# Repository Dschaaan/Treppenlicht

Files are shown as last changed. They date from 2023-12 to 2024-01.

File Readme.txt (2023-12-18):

Treppenlicht

An automatic staircase illumination system using an arduino and LED strips coupled with motion sensors

Content: 
Fritzing File: 	Here the schematic setup of the wiring and the components is shown 
Main Code: 	The code uploaded to the arduino Test Code: For all important components, 
		a testing file will be included Component list: All used components with important explanations

Generall Stuff: 
The idea is to have a motion triggered LED illumination of all steps in the staircase, which only can only be 
activated after a defined time of day. When the bottom motion sensor is activated, the stairs shall be illuminated 
from the bottom to the top and stay on for a defined duration. Afterwards the step lights are turned off in the 
same order as they turned on. Vice verca if the top sensor is activated first.

The working principle is based on the the HC-SR501 PIR Module as a motion sensor, which gives a signal to the 
arduino when activated. The arduino is connected to a PCA9685 16 Channel PWM Driver, which outputs the PMW signal 
for up to 16 steps. To activate the LEDs, they are connected to a logic level MOSFET (IRLZ44N) and respective 
pull-down resistor.

Notes:
- The 12V LEDs are quite bright, but with an additional resistor, the brightness is better suited. 
- Still need a 5V conversion - test the 7508 converter
-

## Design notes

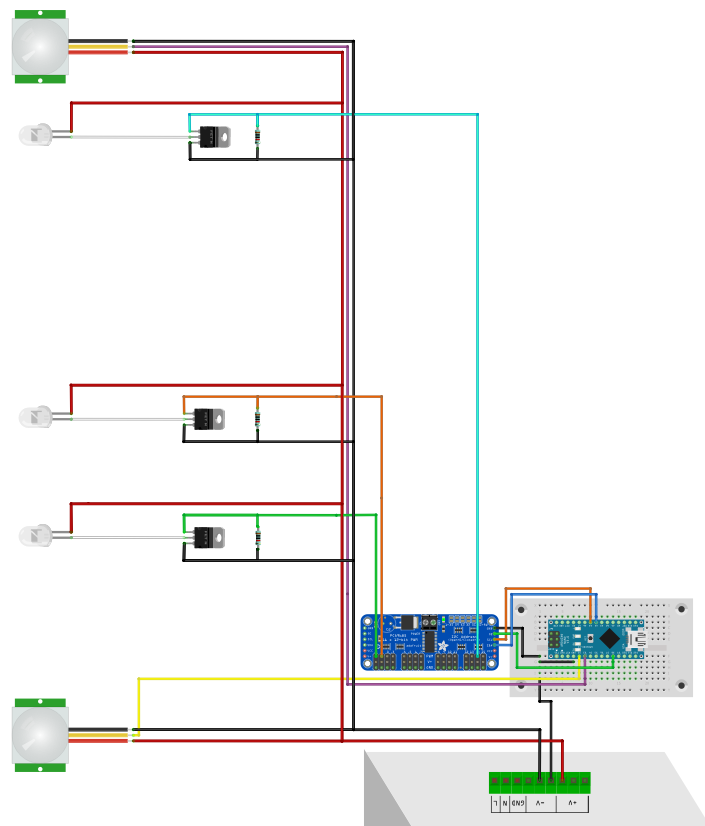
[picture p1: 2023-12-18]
Schaltplan.png

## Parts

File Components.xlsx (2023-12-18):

Treppenlicht Components
Component | # | Price p.p | total | Link | Datasheet
Arduino Nano V3 | 1 | 2.51 € | 2.51 € | https://de.aliexpress.com/item/1005006053215107.html
PIR HC-SR501 | 1 | 2.66 € | 2.66 € | https://de.aliexpress.com/item/1005005970452298.html
PMW PCA9685 16 Kanal | 2 | 2.60 € | 5.20 € | https://www.aliexpress.com/item/1005005973866782.html
Netzteil 200W | 1 | 24.99 € | 24.99 € | https://www.amazon.de/dp/B09Q92KW1H?psc=1&ref=ppx_yo2ov_dt_b_product_details
COB LED 12V 15m | 1 | 25.00 € | 25.00 € | https://www.aliexpress.com/item/1005004635579613.html
MOSFET ILRZ44N | 15 | 1.10 € | 16.50 € | https://www.amazon.de/dp/B0CBKH4XGL?psc=1&ref=ppx_yo2ov_dt_b_product_details
10kO Resistor | 15 |  | 25.00 € | https://www.amazon.de/dp/B08FD4KHP2?psc=1&ref=ppx_yo2ov_dt_b_product_details
Wires & Connectors |  |  |  | https://www.amazon.de/dp/B0B4DFTTDR?psc=1&ref=ppx_yo2ov_dt_b_product_details
 |  |  |  | https://www.amazon.de/dp/B00C7NVYV2?psc=1&ref=ppx_yo2ov_dt_b_product_details
 |  |  |  | https://www.amazon.de/dp/B07D7G8ZJ7?psc=1&ref=ppx_yo2ov_dt_b_product_details
LED Profiles (optional) | 15 | 3.00 € | 44.98 €
 |  |  | 146.84 € | SUMME

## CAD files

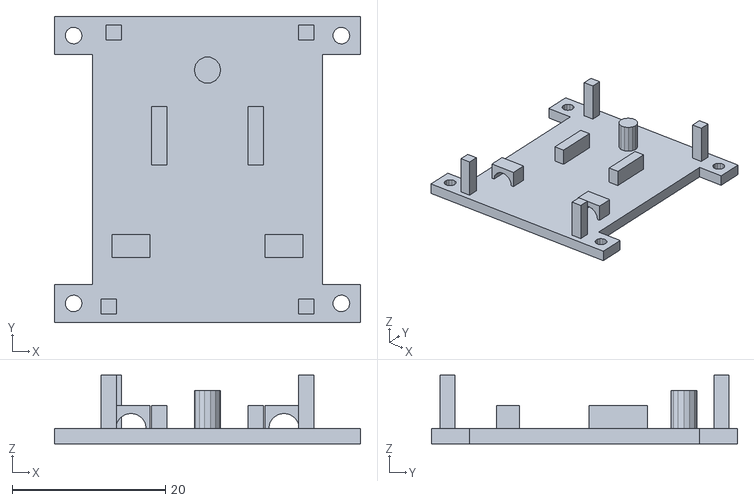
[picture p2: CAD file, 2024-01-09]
STL FIles/Boden Mosfet.stl
40.0 x 40.0 x 9.00

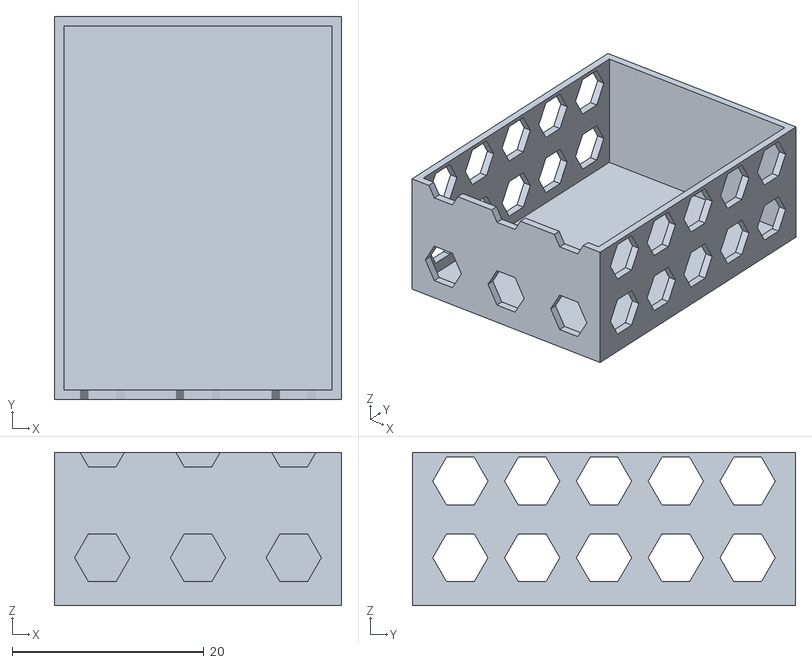
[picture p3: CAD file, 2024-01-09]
STL FIles/Deckel Mosfet.stl
30.0 x 40.0 x 16.0

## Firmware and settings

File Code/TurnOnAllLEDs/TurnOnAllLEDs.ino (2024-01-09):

// 2019 Tobias Kuch GPL 3.0
#include <Wire.h>

#define PWM_Module_Base_Addr 0x40 //10000000b  Das letzte Bit des Adressbytes definiert die auszuführende Operation. Bei Einstellung auf logisch 1  0x41 Modul 2
//wird ein Lesevorgang auswählt, während eine logische 0 eine Schreiboperation auswählt.
#define OE_Pin  8           // Pin für Output Enable
#define PIRA_Pin 2
#define PIRB_Pin 3

#define Num_Stages  15
#define Ontime 3000
#define Delay_Stages  10
#define Delay_ON_to_OFF  30  // Minimum Delay_ON_to_OFF in Seconds

byte Pwm_Channel = 0;
int Pwm_Channel_Brightness = 0;

bool Motion_Trigger_Down_to_Up = false;
bool On_Delay = false;

// interrupt Control
byte A60telSeconds24 = 0;
byte Seconds24;

ISR(TIMER1_COMPA_vect)
{
  A60telSeconds24++;
  if (A60telSeconds24 > 59)
  {
    A60telSeconds24 = 0;
    Seconds24++;
    if (Seconds24 > 150)
    {
      Seconds24 = 0;
    }
  }
}

void ISR_PIR_A()
{
  bool PinState = digitalRead(PIRA_Pin);
  if (PinState)
  {
    Motion_Trigger_Down_to_Up = true; // PIR A ausgelöst
  }
}

void ISR_PIR_B()
{
  bool PinState = digitalRead(PIRB_Pin);
  if (PinState)
  {
    Motion_Trigger_Down_to_Up = true; // PIR B ausgelöst
  }
}

void Init_PWM_Module(byte PWM_ModuleAddr)
{
  pinMode(OE_Pin, OUTPUT);
  digitalWrite(OE_Pin, HIGH); // Active LOW-Ausgangsaktivierungs-Pin (OE).
  Wire.beginTransmission(PWM_ModuleAddr); // Datentransfer initiieren
  Wire.write(0x01);                       // Wähle  Mode 2 Register (Command Register)
  Wire.write(0x04);                       // Konfiguriere Chip: 0x04:  totem pole Ausgang 0x00: Open drain Ausgang.
  Wire.endTransmission();                 // Stoppe Kommunikation - Sende Stop Bit
  Wire.beginTransmission(PWM_ModuleAddr); // Datentransfer initiieren
  Wire.write(0x00);                      // Wähle Mode 1 Register (Command Register)
  Wire.write(0x10);                      // Konfiguriere SleepMode
  Wire.endTransmission();                // Stoppe Kommunikation - Sende Stop Bit
  Wire.beginTransmission(PWM_ModuleAddr); // Datentransfer initiieren
  Wire.write(0xFE);                       // Wähle PRE_SCALE register (Command Register)
  Wire.write(0x03);                       // Set Prescaler. Die maximale PWM Frequent ist 1526 Hz wenn das PRE_SCALEer Regsiter auf "0x03h" gesetzt wird. Standard : 200 Hz
  Wire.endTransmission();                 // Stoppe Kommunikation - Sende Stop Bit
  Wire.beginTransmission(PWM_ModuleAddr); // Datentransfer initiieren
  Wire.write(0x00);                       // Wähle Mode 1 Register (Command Register)
  Wire.write(0xA1);                       // Konfiguriere Chip:  ERrlaube All Call I2C Adressen, verwende interne Uhr,                                           // Erlaube Auto Increment Feature
  Wire.endTransmission();                 // Stoppe Kommunikation - Sende Stop Bit
}


void Init_PWM_Outputs(byte PWM_ModuleAddr)
{
  digitalWrite(OE_Pin, HIGH); // Active LOW-Ausgangsaktivierungs-Pin (OE).
  for ( int z = 0; z < 16 + 1; z++)
  {
    Wire.beginTransmission(PWM_ModuleAddr);
    Wire.write(z * 4 + 6);      // Wähle PWM_Channel_ON_L register
    Wire.write(0x00);                     // Wert für o.g. Register
    Wire.endTransmission();
    Wire.beginTransmission(PWM_ModuleAddr);
    Wire.write(z * 4 + 7);      // Wähle PWM_Channel_ON_H register
    Wire.write(0x00);                     // Wert für o.g. Register
    Wire.endTransmission();
    Wire.beginTransmission(PWM_ModuleAddr);
    Wire.write(z * 4 + 8);   // Wähle PWM_Channel_OFF_L register
    Wire.write(0x00);        // Wert für o.g. Register
    Wire.endTransmission();
    Wire.beginTransmission(PWM_ModuleAddr);
    Wire.write(z * 4 + 9);  // Wähle PWM_Channel_OFF_H register
    Wire.write(0x00);             // Wert für o.g. Register
    Wire.endTransmission();
  }
  digitalWrite(OE_Pin, LOW); // Active LOW-Ausgangsaktivierungs-Pin (OE).
}

void setup()
{
  //Initalisierung
  pinMode(PIRA_Pin, INPUT);
  pinMode(PIRB_Pin, INPUT);
  Serial.begin(9600);
  Wire.begin(); // Initalisiere I2C Bus A4 (SDA), A5 (SCL)
  Init_PWM_Module(PWM_Module_Base_Addr);
  Init_PWM_Outputs(PWM_Module_Base_Addr);
  noInterrupts();
  attachInterrupt(0, ISR_PIR_A, CHANGE);
  attachInterrupt(1, ISR_PIR_B, CHANGE);
  TCCR1A = 0x00;
  TCCR1B = 0x02;
  TCNT1 = 0;      // Register mit 0 initialisieren
  OCR1A =  33353;      // Output Compare Register vorbelegen
  TIMSK1 |= (1 << OCIE1A);  // Timer Compare Interrupt aktivieren
  interrupts();
}

void Down_to_Up_ON()
{
  Pwm_Channel = 0;
  Pwm_Channel_Brightness = 0;
  while (Pwm_Channel < Num_Stages + 1)
  {
    Wire.beginTransmission( PWM_Module_Base_Addr);
    Wire.write(Pwm_Channel * 4 + 8);   // Wähle PWM_Channel_0_OFF_L register
    Wire.write((byte)Pwm_Channel_Brightness & 0xFF);        // Wert für o.g. Register
    Wire.endTransmission();
    Wire.beginTransmission( PWM_Module_Base_Addr);
    Wire.write(Pwm_Channel * 4 + 9);  // Wähle PWM_Channel_0_OFF_H register
    Wire.write((Pwm_Channel_Brightness >> 8));             // Wert für o.g. Register
    Wire.endTransmission();
    if (Pwm_Channel_Brightness < 4095)
    {
      Pwm_Channel_Brightness = Pwm_Channel_Brightness + Delay_Stages;
      if (Pwm_Channel_Brightness > 4095) {
        Pwm_Channel_Brightness = 4095;
      }
    } else if ( Pwm_Channel < Num_Stages + 1)
    {
      Pwm_Channel_Brightness = 0;
      delay(200);
      Pwm_Channel++;
    }

  }
}

void Down_to_Up_OFF()
{
  Pwm_Channel = 0;
  Pwm_Channel_Brightness = 4095;
  while (Pwm_Channel < Num_Stages + 1)
  {
    Wire.beginTransmission( PWM_Module_Base_Addr);
    Wire.write(Pwm_Channel * 4 + 8);   // Wähle PWM_Channel_0_OFF_L register
    Wire.write((byte)Pwm_Channel_Brightness & 0xFF);        // Wert für o.g. Register
    Wire.endTransmission();
    Wire.beginTransmission( PWM_Module_Base_Addr);
    Wire.write(Pwm_Channel * 4 + 9);  // Wähle PWM_Channel_0_OFF_H register
    Wire.write((Pwm_Channel_Brightness >> 8));             // Wert für o.g. Register
    Wire.endTransmission();
    if (Pwm_Channel_Brightness > 0)
    {
      Pwm_Channel_Brightness = Pwm_Channel_Brightness - Delay_Stages;
      if (Pwm_Channel_Brightness < 0) {
        Pwm_Channel_Brightness = 0;
      }
    } else if ( Pwm_Channel < Num_Stages + 1)
    {
      Pwm_Channel_Brightness = 4095;
      delay(200);
      Pwm_Channel++;
    }

  }
}

void loop() {
  Down_to_Up_ON();
  delay(Ontime);
  Down_to_Up_OFF();
}

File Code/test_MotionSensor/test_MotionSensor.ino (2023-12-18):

/* Example code for HC-SR501 PIR motion sensor with Arduino. More info: www.www.makerguides.com */

// Define connection pins:
#define pirPin 2
#define ledPin 13

// Create variables:
int val = 0;
bool motionState = false; // We start with no motion detected.

void setup() {
  // Configure the pins as input or output:
  pinMode(ledPin, OUTPUT);
  pinMode(pirPin, INPUT);

  // Begin serial communication at a baud rate of 9600:
  Serial.begin(9600);
}

void loop() {
  // Read out the pirPin and store as val:
  val = digitalRead(pirPin);

  // If motion is detected (pirPin = HIGH), do the following:
  if (val == HIGH) {
    digitalWrite(ledPin, HIGH); // Turn on the on-board LED.

    // Change the motion state to true (motion detected):
    if (motionState == false) {
      Serial.println("Motion detected!");
      motionState = true;
    }
  }

  // If no motion is detected (pirPin = LOW), do the following:
  else {
    digitalWrite(ledPin, LOW); // Turn off the on-board LED.

    // Change the motion state to false (no motion):
    if (motionState == true) {
      Serial.println("Motion ended!");
      motionState = false;
    }
  }
} 

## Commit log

2023-12-18 Initial version V1. ToDo: Testing of all LEDs, 5V Connection; add MainCode
    [Components.xlsx, Treppenlicht_V2.fzz]
2024-01-09 added testing file for leds
    [Boden Mosfet.stl, Deckel Mosfet.stl]
